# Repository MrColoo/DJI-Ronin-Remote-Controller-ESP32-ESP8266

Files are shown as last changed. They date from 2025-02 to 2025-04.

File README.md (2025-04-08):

# 🎮 DJI Ronin Remote Controller - ESP32/ESP8266




A wireless remote control solution for DJI Ronin gimbals using ESP8266/ESP32 microcontrollers and WebSocket communication.

## 📝 Description

This project enables wireless control of DJI Ronin gimbals through a network connection, utilizing the SBUS protocol. It creates a bridge between a WebSocket client (like Chataigne software) and the Ronin's SBUS input, allowing remote control via gamepad or other input devices.

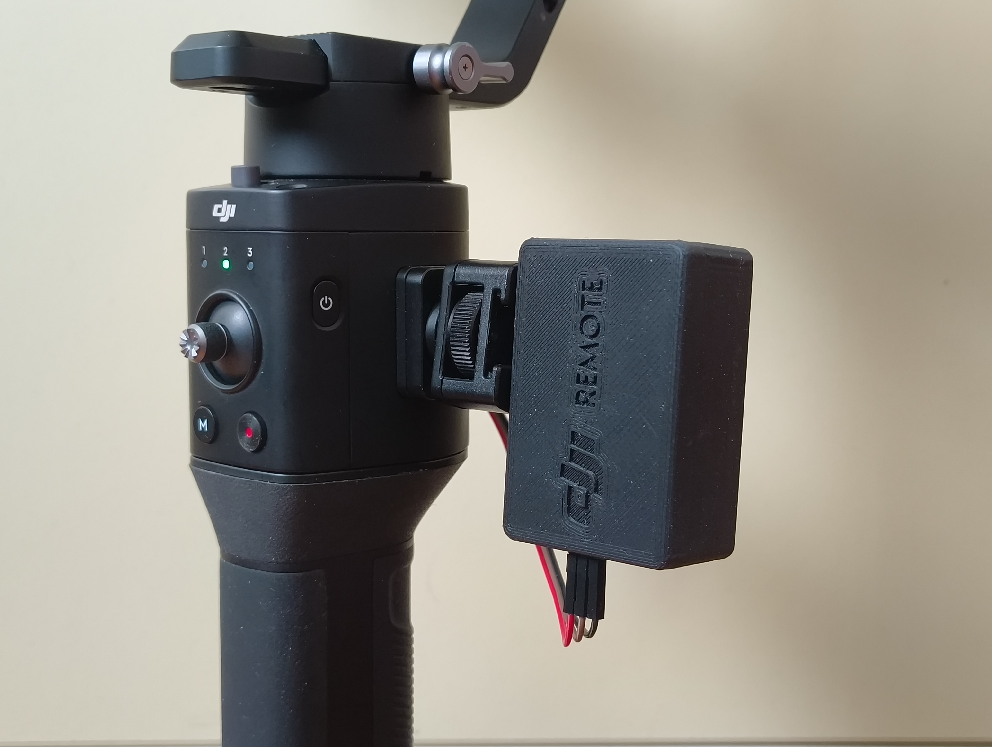
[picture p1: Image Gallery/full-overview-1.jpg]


### ✨ Features

- 🌐 WiFi configuration portal
- 📡 WebSocket server for real-time control
- 💾 Persistent WiFi settings storage
- 📊 Real-time logging interface
- 🔧 Static IP configuration
- 🔄 Easy reset functionality
- 🎮 Compatible with Chataigne software for gamepad input or any WebSocket clients

### 🎥 Demo Video

https://github.com/user-attachments/assets/ff83e8b6-8403-40a6-982f-c90003f82979

## 🛠️ Hardware Requirements

- ESP8266 or ESP32 microcontroller
- DJI Ronin gimbal (tested on Ronin SC, should work with other models)
- Connection cables
- 1x Transistor 2N2222
- 1x 1K Resistor
- 1x 5K Resistor  
NOTE: Have a look to wiring schema image

## 📋 Installation Guide

### 1. Hardware Setup

1. Connect the ESP board to the Ronin's SBUS port:
   - SBUS signal → Transistor 2N2222 or serial inverter (look at wiring schema) -> GPIO pin (as defined in code)
   - GND → GND
   - 5V → 5V (if needed)

NOTE: Have a look to wiring schema image

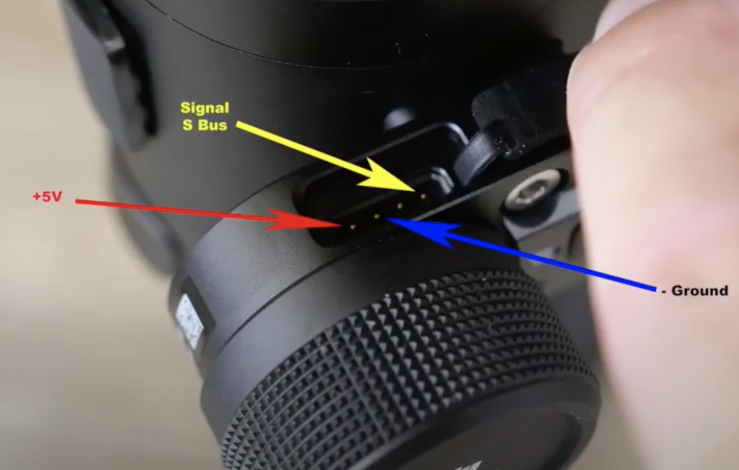
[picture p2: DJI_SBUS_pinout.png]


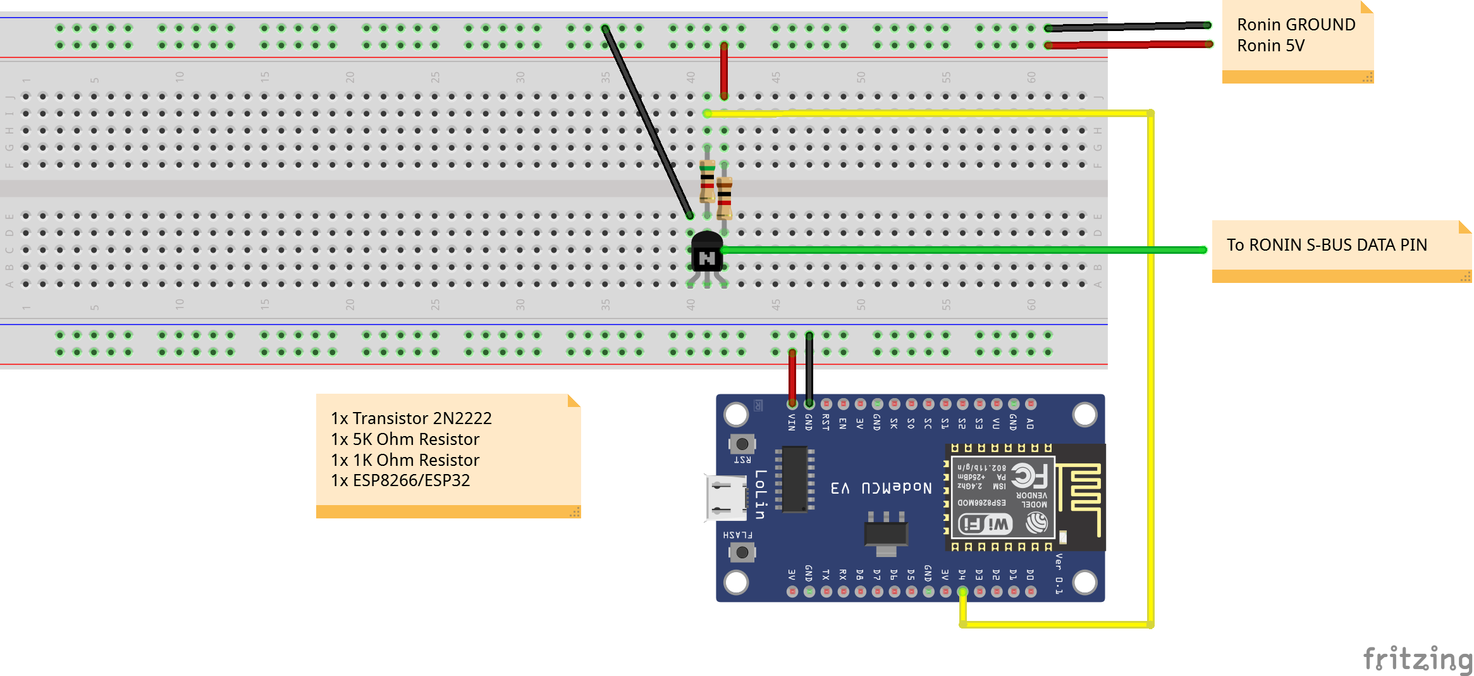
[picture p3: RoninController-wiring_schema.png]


### 2. Software Setup

1. Install required Arduino libraries:
   - ESP8266WiFi
   - ESP8266WebServer
   - DNSServer
   - EEPROM
   - WebSocketsServer
   - Ronin_SBUS // Copy the library folder under Code folder here on github and put into your libraries folder

2. Upload the code to your ESP device

### 3. Initial Configuration

1. Power up the device
2. Connect to the WiFi network "RoninControl_Setup"
3. Automatically the captive portal should open up, if it doesn't, open a web browser and navigate to `192.168.4.1`
4. Configure your WiFi settings:
   - Enter your network SSID and password
   - Optionally configure static IP
5. Save and wait for the device to restart
  
NOTE: ✔ If the ESP connects successfully to the wifi, the generated wifi will disappear.
     ❌ If the ESP can't connect to wifi after some attempts, it will restart in setup mode

## 🎮 Usage

### Normal Operation

1. The device will connect to your configured WiFi network
2. Access the web interface using the device's IP address
3. Available pages:
- Status page: Shows connection info and device status
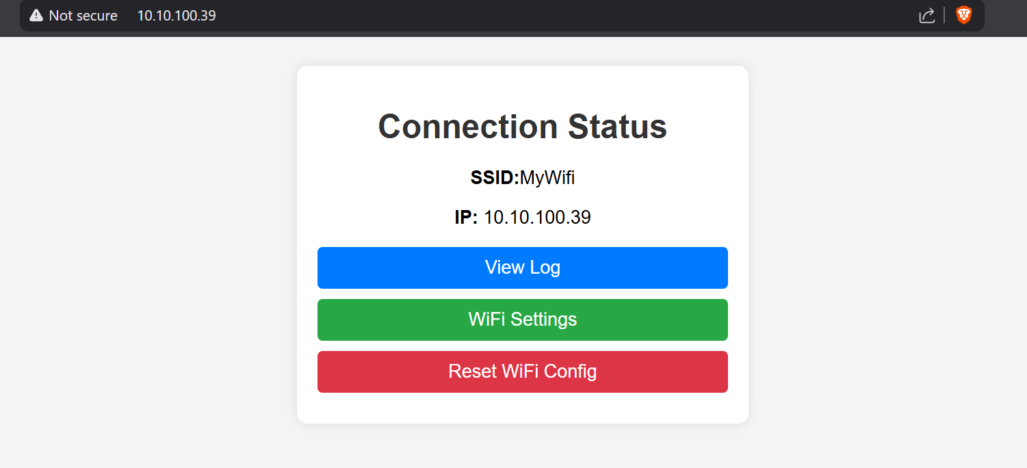
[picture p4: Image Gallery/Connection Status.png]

- Log page: Real-time operation logs
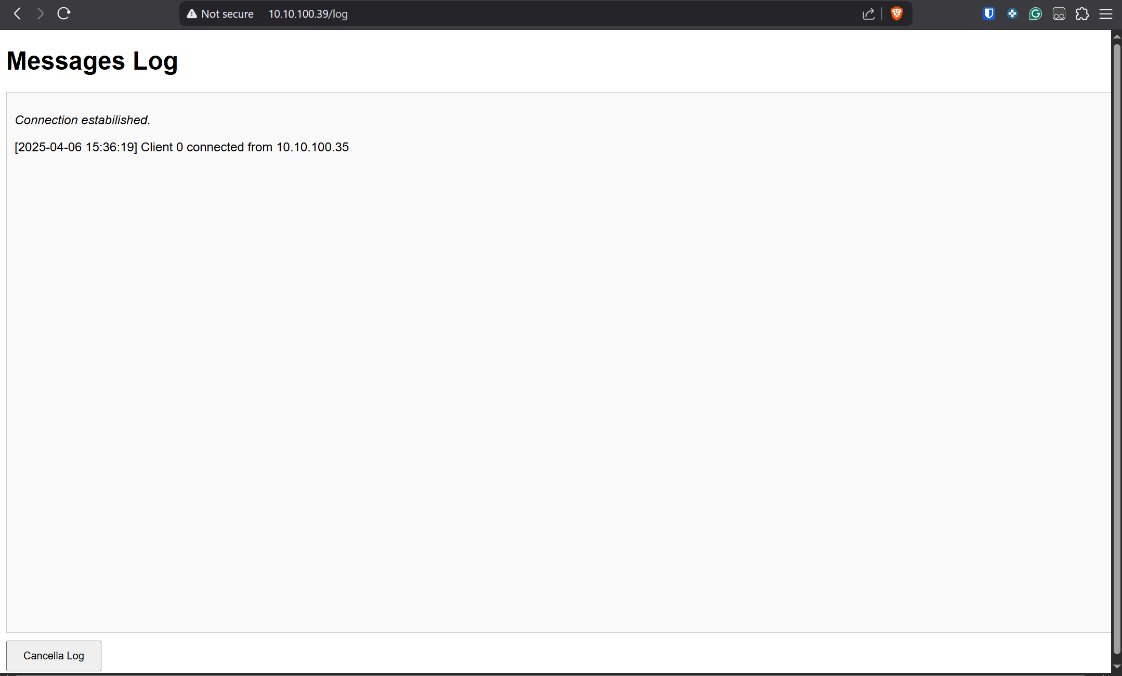
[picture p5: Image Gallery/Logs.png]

- WiFi Configuration: Network settings
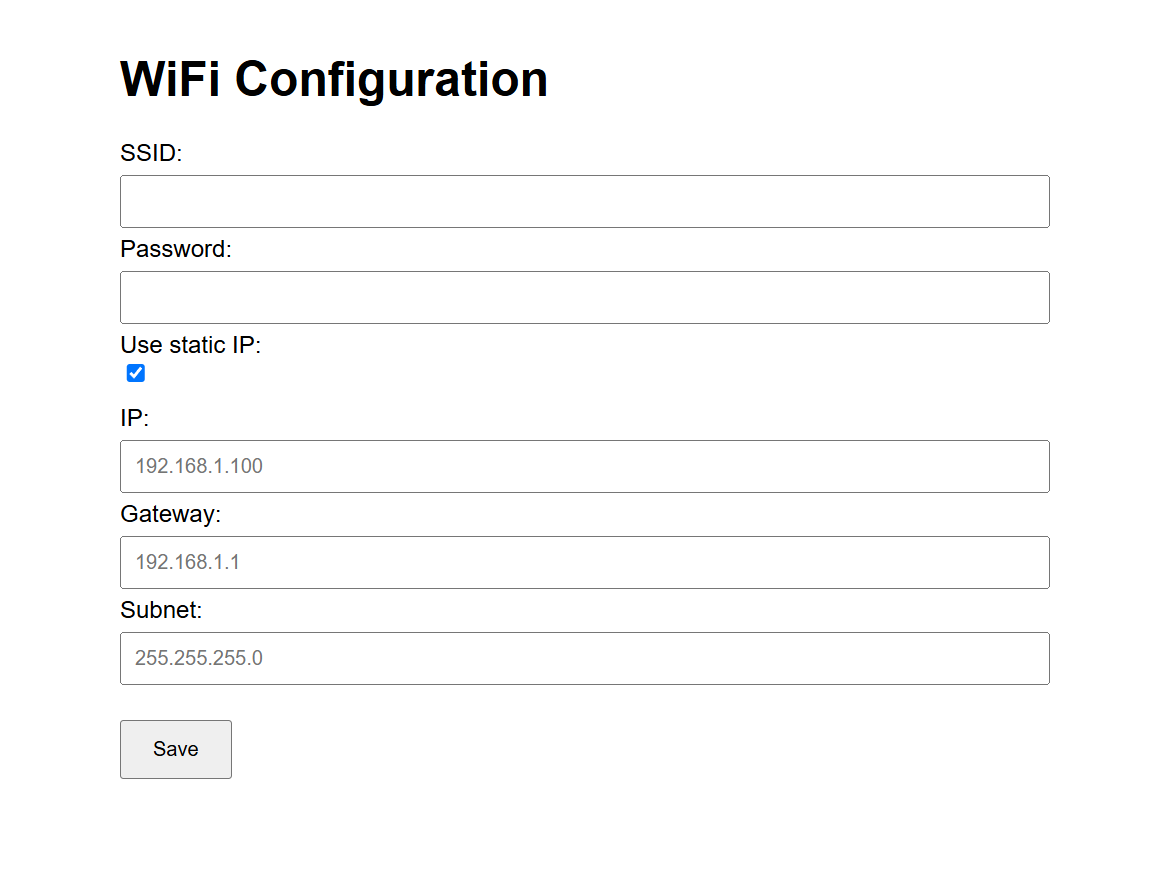
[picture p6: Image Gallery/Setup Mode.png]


### WebSocket Control

1. Connect to the WebSocket server on port 81
2. Send commands in format: `chX:VALUE` where:
- X: Channel number (1-16)
- VALUE: Position value (352-1696)

Example: `ch1:1024` sets channel 1 to center position

### Using with Chataigne

1. Download from this repo the setup file: `RONIN_CONTROL_Chataigne_SetupFile.noisette`
2. Configure Chataigne's WebSocket module to connect to the device
3. Map gamepad inputs to WebSocket messages
   -> Use the following value ranges:
      - Minimum: 352
      - Center: 1024
      - Maximum: 1696

NOTE: For Ronin SC I made only PAN and TILT work (channels 1 and 2)

## 🔧 Technical Details

### Key Components

- **WiFi Configuration**: Stores network settings in EEPROM
- **WebSocket Server**: Handles real-time control commands
- **SBUS Protocol**: Communicates with Ronin gimbal
- **Web Interface**: Provides configuration and monitoring

## 🐛 Known Bugs

1. The gimbal mode 2 is set by default and it is not changeable
2. If only one websocket movement command is sent (for ex. joystick stick all to the right), the gimbal will move and then stop after some seconds, instead of continuing to move.

## 🚧 Unimplemented Features (Work in progress)

1. Gimbal mode selector
2. Gimbal Recenter
3. Start and Stop Recording
4. Remote controlled motorized Zoom / Focus
5. Complete debug feature through logs
6. Extend complete compatibility to other Ronin models (right know only Ronin SC is supported without code modifications)

## ⚠️ Important Notes

- Tested primarily with DJI Ronin SC, but should work with other models, you may will have to adjust s-bus values in the Ronin_SBUS library
- Ensure a stable WiFi connection for reliable control
- Keep within range of the WiFi network
- Monitor the log interface for debugging

## 📚 Library

- Ronin_SBUS is a library I wrote, starting from the original [BMC_SBUS](https://github.com/boldstelvis/BMC_SBUS) library. Thanks to the developer.

## 🤝 Contributing

Contributions, issues, and feature requests are welcome!

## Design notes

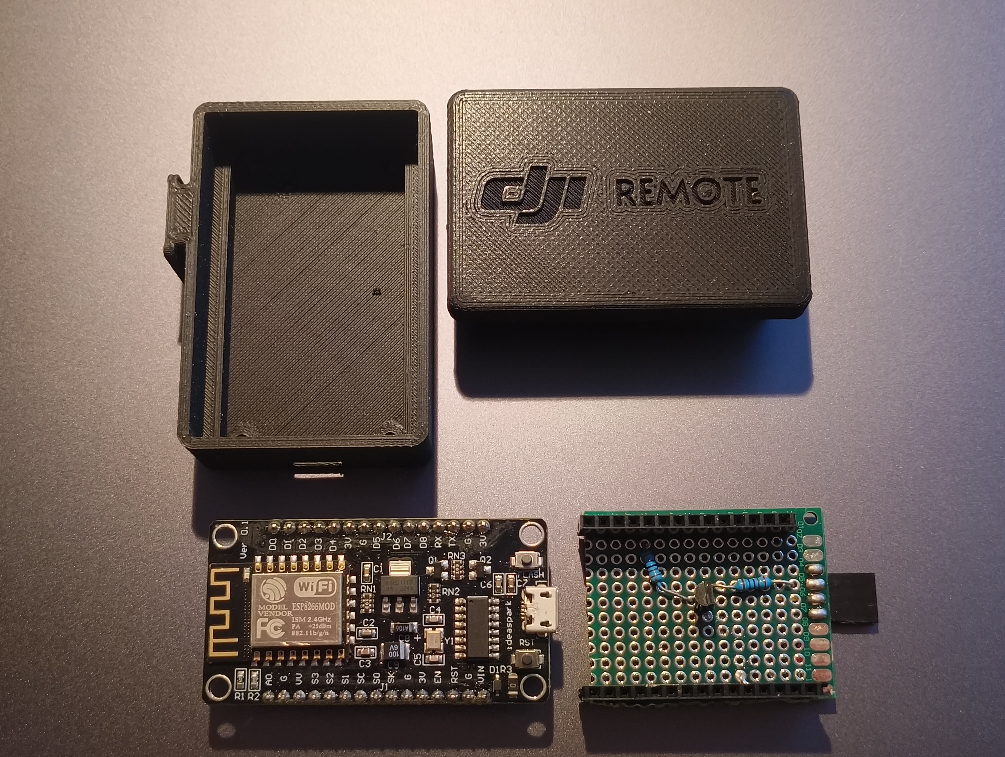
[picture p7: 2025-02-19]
Image Gallery/device-overview-2.jpg

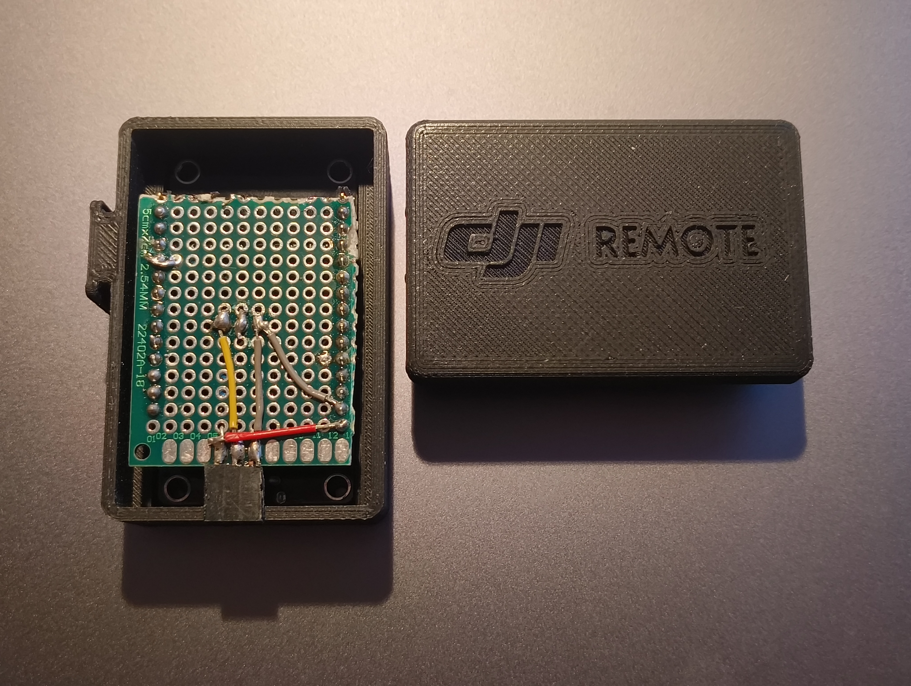
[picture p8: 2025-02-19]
Image Gallery/device-overview-3.jpg

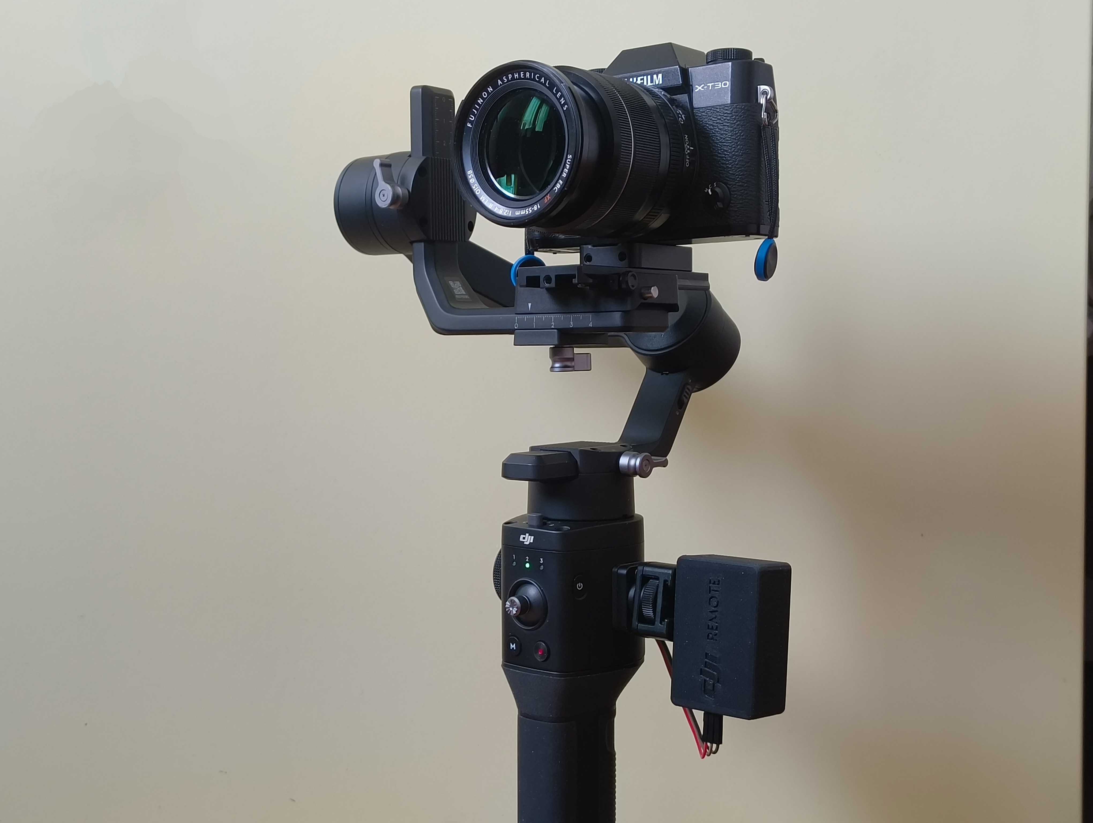
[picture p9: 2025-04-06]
Image Gallery/full-overview-2.jpg

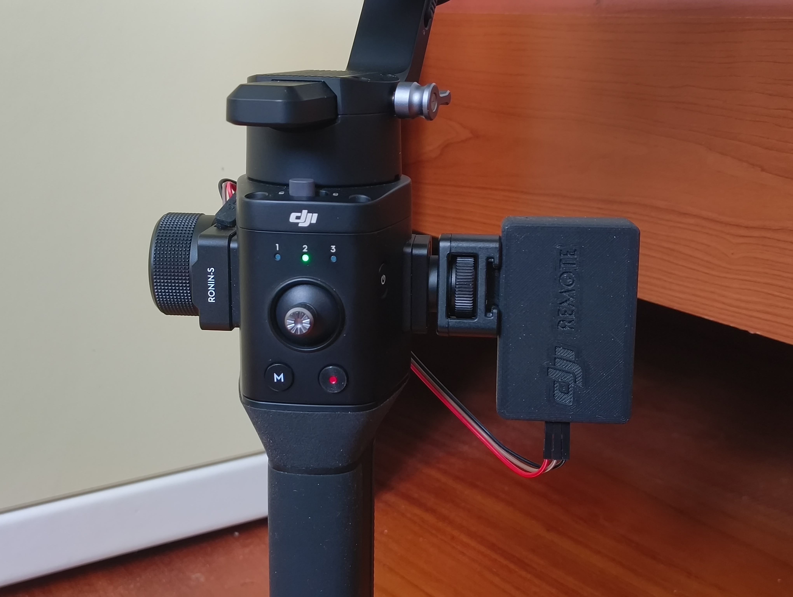
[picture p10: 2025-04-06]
Image Gallery/full-overview-5.jpg

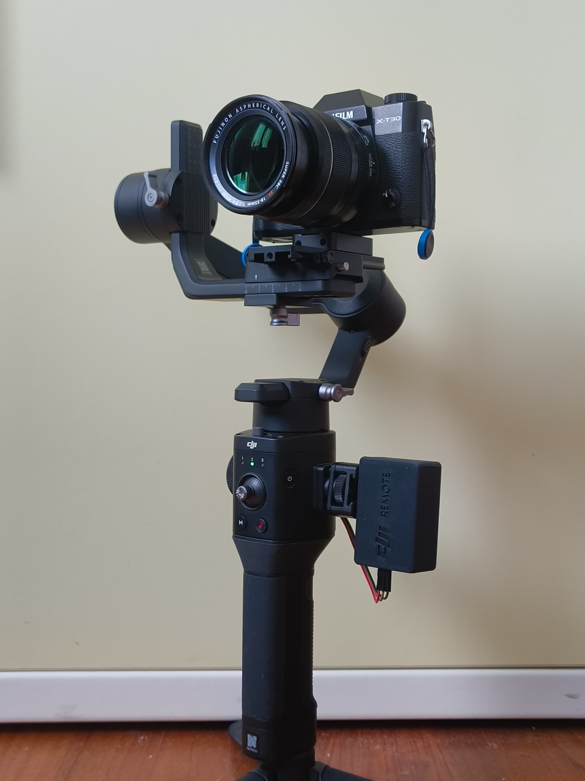
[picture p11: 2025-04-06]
Image Gallery/full-overview-3.jpg

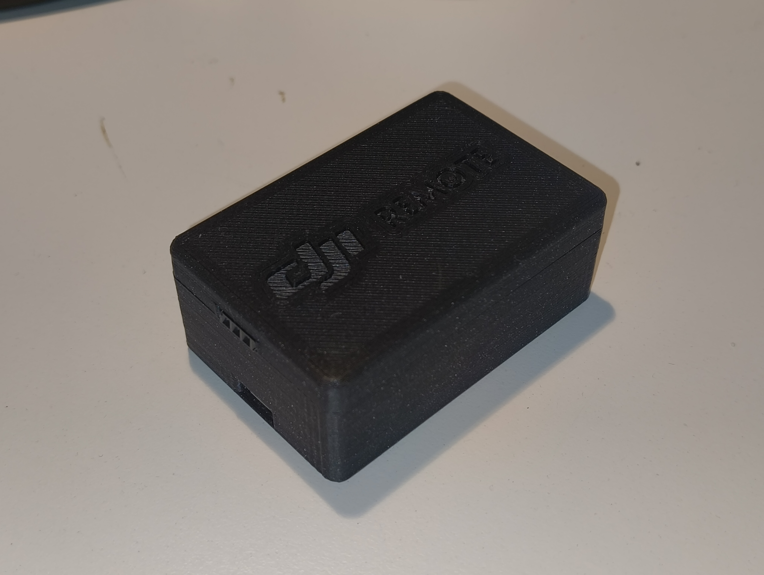
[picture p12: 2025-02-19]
Image Gallery/device-overview-4.jpg

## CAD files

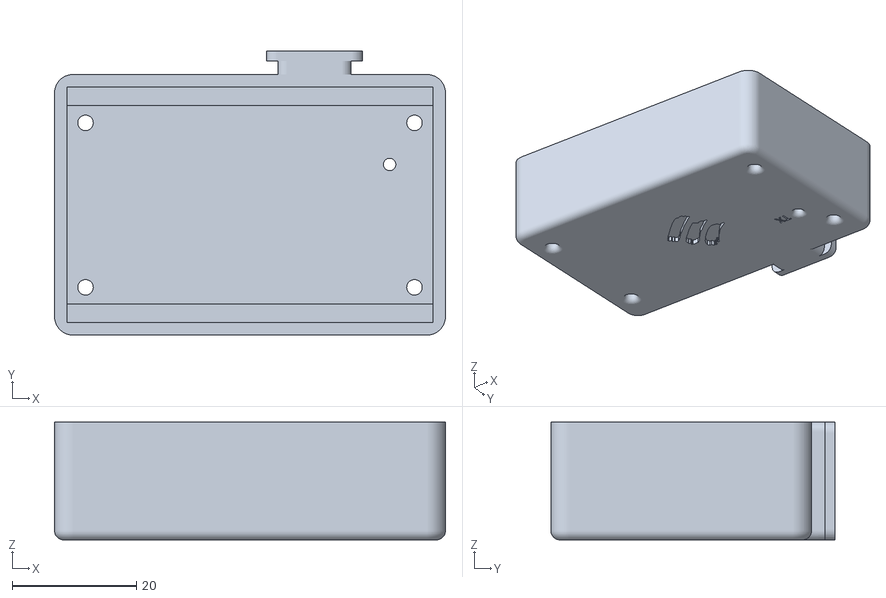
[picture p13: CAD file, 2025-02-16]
3D_CASE/Bottom CASE.stl
63.0 x 45.8 x 19.0

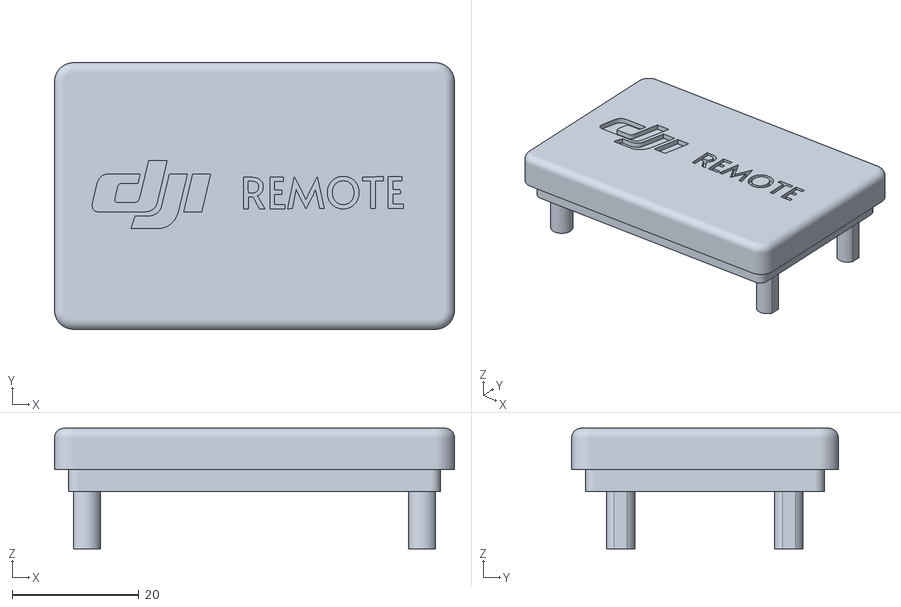
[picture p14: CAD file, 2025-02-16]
3D_CASE/Up Cover CASE.stl
63.0 x 42.0 x 19.0

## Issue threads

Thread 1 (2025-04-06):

A-B scene switching, connection details

abrman, 2025-04-06:
Hey! This project and readme looks incredibly well done. I'm sort-of using this to make an informed purchase of a DJI Ronin + Sony mirrorless camera or PTZ camera for live event streaming. I would love to go the Ronin + Camera as it's more versatile if PTZ like controls work, otherwise PTZ camera it is.

1. Is it possible to do A-B scene switching using this? (Preset pitch tilt zoom and transition to that point) I'm thinking sending three self-stored values via ws should work but due to lack of experience I'm asking specifically. - I suppose it's designed to work with Chatsigne software - will need to look into this

2. How does it connect to the Ronin - the attached images are very informative but once the connector leaves the ESP32/ESP8266 how does it connect to the ronin? Do I need to get an additional wire?

3. How's the reliability of the connection. I've had esp32 chips become unresponsive for some IOT applications in the past requiring reboot. Would it be possible to do a video demo on YouTube?

Love the work you did on this!
Thank you!

abrman, 2025-04-07:
Thank you for all the additional details. I've pondered on it for a bit as to whether it's a path forward for me.

From what you're saying it seems like the controls are setting a motor strength rather than monitoring Pitch Yaw Roll, very much like something a gimbal would be controlled by haha. I suppose internally the gimbal has to have an accelerometer or a gyroscope but the data isn't published by the Ronin.

I'm wondering if an additional gyroscope could achieve the functionality I'm seeking where it could feed the motor strength instead of user controls. I've been also toying with the idea of visual reference points and use the video signal to feed the controller data until desired view is achieved (rather complex even if permanent install in a studio is considered due to lighting and subjects so I'm not inclined to go this route)

https://randomnerdtutorials.com/esp32-mpu-6050-accelerometer-gyroscope-arduino/

The gyro would have to be installed somewhere on the camera. Ultimately the orientation shouldn't matter as the output can be transformed to zero out reading when pointing straight ahead. When "sceene switching" just zero out to a different point and the camera should transition assuming the gyro values influence the data passed to the gimbal.

Wiring is potentially an issues unless power is somehow received from the camera and data fed over Bluetooth back to the controller, although if HDMI wire is already connected to the camera, this might not be a big issue due to the wire restraint already being there, and an additional wire should be a problem.

Just sharing thought up until now. Let me know if you have any thoughts on anything said. - What are the limitations on roll. You do mention Pan and Tilt, is roll also configurable or is that managed automatically by the ronin keeping level with the horizon. What are the limitations for zoom control? I'm speaking out of lack of experience but my understanding is that zoom can be external via a motor (DJI has one I think?) or the lens needs to have motorized zoom. What are the obstacles in controlling zoom if that was a desired feature. Consider DJI Ronin Zoom control. Does it normally connect in the same place we're connecting for the S-Bus data pin? Would it be controllable?

Thank you for your work on this! I'm excited for this project as it seems like the best solution of all the other GitHub projects tacking the Ronin PTZ control problem.

MrColoo, 2025-04-08:
Excellent thoughts and ideas!

> I'm wondering if an additional gyroscope could achieve the functionality I'm seeking where it could feed the motor strength instead of user controls

As I said before, the ronin does not send any data, so if it has any kind of gyroscope or accelerometer is not usable.
This said, it is possible to add an external gyro to the gimbal and as you said before should be installed on the top or bottom of the camera. It will make the project more complicated, but everything is possible. On the camera mount there are two holes where it could be screwed on, but there would be other cables other than the HDMI (if they are thin, it should not be a problem)

> I've been also toying with the idea of visual reference points and use the video signal to feed the controller data until desired view is achieved (rather complex even if permanent install in a studio is considered due to lighting and subjects so I'm not inclined to go this route)

I think this would be a little overkill right now and would require more computational power to process all the images and algorithms...

>  What are the limitations on roll.
Unfortunately, I wasn't able to control the Roll axis through the SBUS interface on my Ronin SC, and some discussions on the DJI Forum confirm this, but it should work on the Ronin S series.

> What are the limitations for zoom control?
The stock follow focus / zoom motor is not usable through SBUS in any Ronin gimbal (idk why DJI does this to us...), so to implement this, we could use an external stepper motor mounted on the original bracket and attached directly to the ESP.

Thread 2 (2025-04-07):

S-BUS Connection 4pin, but 3 wires

paulprinke, 2025-04-07:
I am trying to get this setup locally and I cant find a map of what the layout of the SBUS on the gimbal (focus knob) to then match your wiring schematic.  Do you have this handy or could you add some additional details to your README?

I think I have the wiring done, but concerned connecting to just random pins to try.  (Using an ESP32C3)

MrColoo, 2025-04-08:
Hi! Thanks for your interest for the project. I've just updated the readme with more images about the wiring and the pinout of the ronin focus know. Let me know if now is more understandable

Closed 2025-04-08.

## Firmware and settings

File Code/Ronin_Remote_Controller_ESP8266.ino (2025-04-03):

#include <ESP8266WiFi.h>
#include <ESP8266WebServer.h>
#include <DNSServer.h>
#include <EEPROM.h>
#include <WebSocketsServer.h>
#include <Ronin_SBUS.h>

// Access Point Setup
const char* AP_SSID = "RoninControl_Setup";
const byte DNS_PORT = 53;
IPAddress apIP(192, 168, 4, 1);

// Server and DNS
ESP8266WebServer webServer(80);
DNSServer dnsServer;

// WebSockets Server
WebSocketsServer webSocket = WebSocketsServer(81); // Porta 81 per WebSockets

// Struct to save wifi config
struct WifiConfig {
    char wifi_ssid[32];
    char wifi_password[64];
    bool use_static_ip;
    IPAddress static_ip;
    IPAddress gateway;
    IPAddress subnet;
    uint8_t config_set;  // Flag per verificare se la configurazione è stata impostata
};

// Initialize wificonfig struct
WifiConfig wificonfig;

// Initialize SBUS interface
Ronin_SBUS mySBUS;

// Constants used to define min, mid and max values & frame delay
const int sbusMID         = 1024;   // Neutral val
const int sbusMIN         = 352;    // Min usable for analog val and switch val
const int sbusMAX         = 1696;   // Max usable for analog val and switch val
const int sbusWAIT        = 10;     // Frame timing delay in msecs

// Function to send logs throw WebSocket with timestamp, visible in webpage/log
void sendLog(String message) {
    // Get current time
    time_t now = time(nullptr);
    struct tm* timeinfo = localtime(&now);
    
    // Timestamp format
    char timeString[20];
    strftime(timeString, sizeof(timeString), "%Y-%m-%d %H:%M:%S", timeinfo);
    
    // Write formatted message
    String formattedMessage = String("[") + String(timeString) + "] " + message;
    webSocket.broadcastTXT(formattedMessage);
}

void setup() {
    // Inizialize EEPROM
    EEPROM.begin(512);
    // Initialize USB serial for debug
    // Serial.begin(9600); // Uncomment if you want to debug via serial console

    // Load saved wifi settings
    loadWifiConfig();

    // Initialize SBUS 
    mySBUS.begin();

    if (wificonfig.config_set != 1) {
        startSetupMode();
    } else {
        startNormalMode();
    }
}

// Function to load wifi config from the struct
void loadWifiConfig() {
    EEPROM.get(0, wificonfig);
    if (wificonfig.config_set != 1) {
        wificonfig.config_set = 0;
        wificonfig.use_static_ip = false;
        strcpy(wificonfig.wifi_ssid, ""); // Vuoto per configurazione
        strcpy(wificonfig.wifi_password, ""); // Vuoto per configurazione
        wificonfig.static_ip = IPAddress(192, 168, 1, 200);
        wificonfig.gateway = IPAddress(192, 168, 1, 1);
        wificonfig.subnet = IPAddress(255, 255, 255, 0);
    }
}

void saveWifiConfig() {
    EEPROM.put(0, wificonfig);
    EEPROM.commit();
}

// Function to start the ESP in setup mode --> generate open wifi ("RoninControl_Setup") to set up network settings
void startSetupMode() {
    WiFi.mode(WIFI_AP);
    WiFi.softAPConfig(apIP, apIP, IPAddress(255, 255, 255, 0));
    WiFi.softAP(AP_SSID);
    dnsServer.start(DNS_PORT, "*", apIP);

    webServer.on("/", handleSetupRoot);
    webServer.on("/configure", handleConfigure);
    webServer.on("/reset", handleReset);
    webServer.onNotFound([]() { 
        webServer.sendHeader("Location", "/", true);
        webServer.send(302, "text/plain", ""); 
    });
    webServer.begin();
    sendLog("Setup mode started");
}

// Function to start the ESP in normal mode --> if it cannot connect within 25 attemps, it will restart in setup mode
void startNormalMode() {
    WiFi.mode(WIFI_STA);
    if (wificonfig.use_static_ip) {
        WiFi.config(wificonfig.static_ip, wificonfig.gateway, wificonfig.subnet);
    }
    WiFi.begin(wificonfig.wifi_ssid, wificonfig.wifi_password);
    sendLog("Connecting to wifi: " + String(wificonfig.wifi_ssid));
    int attempts = 0;
    while (WiFi.status() != WL_CONNECTED && attempts < 25) {
        delay(1000);
        sendLog("Connection attemp #" + attempts);
        attempts++;
    }
    if (WiFi.status() == WL_CONNECTED) {
        configTime(3600, 0, "pool.ntp.org", "time.nist.gov");

        sendLog("Connected to " + String(wificonfig.wifi_ssid));
        sendLog("IP: " + WiFi.localIP().toString());

        // Setting up WebServer routes
        webServer.on("/", handleStatusRoot);
        webServer.on("/configure", handleConfigure);
        webServer.on("/reset", handleReset);
        webServer.on("/log", handleLogPage);
        webServer.on("/wificonfig", handleWifiConfig);
        webServer.begin();

        // Initialize WebSocket
        webSocket.begin();
        webSocket.onEvent(webSocketEvent);
        sendLog("WebSocket Server started on port 81");
    } else {
        sendLog("Connection failed, starting setup mode");
        handleReset();
        startSetupMode();
    }
}

// Setup page handling
void handleSetupRoot() {
    webServer.send(200, "text/html",
        "<!DOCTYPE html>"
        "<html>"
        "<head>"
        "  <title>WiFi Configuration</title>"
        "  <style>"
        "    body { font-family: Arial, sans-serif; max-width: 600px; margin: auto; padding: 20px; }"
        "    input[type=text], input[type=password] { width: 100%; padding: 8px; margin: 5px 0; }"
        "    input[type=submit] { padding: 10px 20px; }"
        "  </style>"
        "</head>"
        "<body>"
        "  <h1>WiFi Configuration</h1>"
        "  <form id='wifiForm' action='/configure' method='POST'>"
        "    <label>SSID:</label><br>"
        "    <input type='text' name='ssid' required><br>"
        "    <label>Password:</label><br>"
        "    <input type='password' name='password' required><br>"
        "    <label>Use static IP:</label><br>"
        "    <input type='checkbox' name='static_ip' id='static_ip'><br>"
        "    <div id='static_ip_fields' style='display:none; margin-top:10px;'>"
        "      <label>IP:</label><br>"
        "      <input type='text' name='ip' placeholder='192.168.1.100'><br>"
        "      <label>Gateway:</label><br>"
        "      <input type='text' name='gateway' placeholder='192.168.1.1'><br>"
        "      <label>Subnet:</label><br>"
        "      <input type='text' name='subnet' placeholder='255.255.255.0'><br>"
        "    </div>"
        "    <br>"
        "    <input type='submit' value='Save'>"
        "  </form>"
        "  <script>"
        "    document.getElementById('static_ip').addEventListener('change', function() {"
        "      document.getElementById('static_ip_fields').style.display = this.checked ? 'block' : 'none';"
        "    });"
        "    document.getElementById('wifiForm').addEventListener('submit', function(event) {"
        "      alert('Configuration Saved!\\nThe device will reboot and try to connect to WiFi.\\nIf something goes wrong, it will restart in setup mode.');"
        "    });"
        "  </script>"
        "</body>"
        "</html>"
    );
}

// Status page handling
void handleStatusRoot() {
    String page = "<!DOCTYPE html>"
                  "<html>"
                  "<head>"
                  "<title>Connection Status</title>"
                  "<style>"
                  "  body { font-family: Arial, sans-serif; text-align: center; padding: 20px; background-color: #f4f4f4; }"
                  "  .container { max-width: 400px; margin: auto; background: white; padding: 20px; border-radius: 10px; box-shadow: 0 0 10px rgba(0,0,0,0.1); }"
                  "  h1 { color: #333; }"
                  "  p { font-size: 18px; }"
                  "  .button { display: block; width: 100%; padding: 10px; margin: 10px 0; border: none; border-radius: 5px; font-size: 18px; text-decoration: none; cursor: pointer; text-align: center; }"
                  "  .btn-log { background-color: #007bff; color: white; }"
                  "  .btn-config { background-color: #28a745; color: white; }"
                  "  .btn-reset { background-color: #dc3545; color: white; }"
                  "</style>"
                  "</head>"
                  "<body>"
                  "<div class='container'>"
                  "  <h1>Connection Status</h1>"
                  "  <p><strong>SSID:</strong> " + String(WiFi.SSID()) + "</p>"
                  "  <p><strong>IP:</strong> " + WiFi.localIP().toString() + "</p>"
                  "  <button class='button btn-log' onclick='logRedirect()'>View Log</button>"
                  "  <button class='button btn-config' onclick='configRedirect()'>WiFi Settings</button>"
                  "  <button class='button btn-reset' onclick='confirmReset()'>Reset WiFi Config</button>"
                  "</div>"
                  "<script>"
                  "  function confirmReset() {"
                  "    if (confirm('WiFi configuration will be reset and the device will reboot in setup mode. Continue?')) {"
                  "      setTimeout(() => { window.location.href = '/reset'; }, 500);"
                  "      setTimeout(() => { window.close(); }, 1000);"
                  "    }"
                  "  }"
                  "  function logRedirect() {"
                  "     window.location.href = '/log';"
                  "  }"
                  "  function configRedirect() {"
                  "     window.location.href = '/wificonfig';"
                  "  }"
                  "</script>"
                  "</body>"
                  "</html>";

    webServer.send(200, "text/html", page);
}

void handleWifiConfig() {
    String page = "<!DOCTYPE html>"
        "<html>"
        "<head>"
        "  <title>WiFi Configuration</title>"
        "  <style>"
        "    body { font-family: Arial, sans-serif; max-width: 600px; margin: auto; padding: 20px; }"
        "    input[type=text], input[type=password] { width: 100%; padding: 8px; margin: 5px 0; }"
        "    input[type=submit] { padding: 10px 20px; }"
        "  </style>"
        "</head>"
        "<body>"
        "  <h1>WiFi Configuration</h1>"
        "  <form id='wifiForm' action='/configure' method='POST'>"
        "    <label>SSID:</label><br>"
        "    <input type='text' name='ssid' value='" + String(wificonfig.wifi_ssid) + "' disabled><br>"
        "    <div id='static_ip_fields' style='display:block; margin-top:10px;'>"
        "      <label>IP:</label><br>"
        "      <input type='text' name='ip' value='" + WiFi.localIP().toString() + "' required><br>"
        "      <label>Gateway:</label><br>"
        "      <input type='text' name='gateway' value='" + WiFi.gatewayIP().toString() + "' required><br>"
        "      <label>Subnet:</label><br>"
        "      <input type='text' name='subnet' value='" + WiFi.subnetMask().toString() + "' required><br>"
        "    </div>"
        "    <br>"
        "    <input type='submit' value='Save'>"
        "  </form>"
        "  <script>"
        "    document.getElementById('wifiForm').addEventListener('submit', function(event) {"
        "      alert('Configuration Saved!\\nThe device will reboot and try to connect to WiFi.\\nIf something goes wrong, it will restart in setup mode.');"
        "    });"
        "  </script>"
        "</body>"
        "</html>";

    webServer.send(200, "text/html", page);
}

// Log page handling
void handleLogPage() {
    String page = R"rawliteral(
<!DOCTYPE html>
<html>
<head>
    <title>Messages Log</title>
    <style>
        body { font-family: Arial, sans-serif; }
        #logs { width: 100%; height: 80vh; border: 1px solid #ccc; overflow-y: scroll; padding: 10px; background-color: #f9f9f9; }
        #clearButton { margin-top: 10px; padding: 10px 20px; }
        button { cursor: pointer; }
    </style>
</head>
<body>
    <h1>Messages Log</h1>
    <div id="logs"></div>
    <button id="clearButton">Cancella Log</button>

    <script>
        let socket = new WebSocket('ws://' + location.hostname + ':81/');
        let logs = document.getElementById('logs');
        let clearButton = document.getElementById('clearButton');

        socket.onopen = function(event) {
            logs.innerHTML += '<p><em>Connection estabilished.</em></p>';
        };

        socket.onmessage = function(event) {
            logs.innerHTML += '<p>' + event.data + '</p>';
            logs.scrollTop = logs.scrollHeight; // Scorri automaticamente verso il basso
        };

        socket.onclose = function(event) {
            logs.innerHTML += '<p><em>Connection closed.</em></p>';
        };

        clearButton.addEventListener('click', function() {
            logs.innerHTML = '';
            // Optional: Send a message to server when clear button is pressed
            // socket.send('clear');
        });
    </script>
</body>
</html>
)rawliteral";

    webServer.send(200, "text/html", page);
}

// WiFi Configuration handling (receives data from POST form)
void handleConfigure() {
    // Form Data
    String ssid = webServer.arg("ssid");
    String password = webServer.arg("password");
    bool use_static_ip = webServer.hasArg("static_ip");
    String ip = webServer.arg("ip");
    String gateway = webServer.arg("gateway");
    String subnet = webServer.arg("subnet");

    if(wificonfig.config_set == 0){
      if (ssid.length() > 0 && password.length() > 0) {
        strncpy(wificonfig.wifi_ssid, ssid.c_str(), sizeof(wificonfig.wifi_ssid));
        strncpy(wificonfig.wifi_password, password.c_str(), sizeof(wificonfig.wifi_password));
        wificonfig.use_static_ip = use_static_ip;
        if (use_static_ip) {
            wificonfig.static_ip = parseIPAddress(ip);
            wificonfig.gateway = parseIPAddress(gateway);
            wificonfig.subnet = parseIPAddress(subnet);
        }
        wificonfig.config_set = 1;
      } else {
        webServer.send(400, "text/plain", "SSID and Password are required.");
        return;
      }
    }else{
      if (ip.length() > 0 && gateway.length() > 0 && subnet.length() > 0) {
        wificonfig.static_ip = parseIPAddress(ip);
        wificonfig.gateway = parseIPAddress(gateway);
        wificonfig.subnet = parseIPAddress(subnet);
        wificonfig.use_static_ip = true;
      } else {
        webServer.send(400, "text/plain", "IP Address, Gateway and Subnet are required.");
        return;
      }
    }
      
      saveWifiConfig();
      sendLog("WiFi config saved. Reboot...");
      webServer.sendHeader("Location", "/", true);
      webServer.send(302, "text/plain", "WiFi config saved. Reboot...");
      delay(1000);
      ESP.restart();
}

// Parsing IP from string
IPAddress parseIPAddress(String ip) {
    IPAddress result;
    result.fromString(ip);
    return result;
}

// Handling reset via web
void handleReset() {
    // Configurations reset
    memset(&wificonfig, 0, sizeof(wificonfig));
    saveWifiConfig();
    sendLog("WiFi config resetted. Reboot...");
    webServer.sendHeader("Location", "/", true);
    webServer.send(302, "text/plain", "WiFi config resetted. Reboot...");
    delay(1000);
    ESP.restart();
}

// Handling WebSocket events
void webSocketEvent(uint8_t num, WStype_t type, uint8_t * payload, size_t length) {
    switch(type) {
        case WStype_DISCONNECTED:
            sendLog("Client WebSocket " + String(num) + " Disconnected");
            break;
        case WStype_CONNECTED: {
            IPAddress ip = webSocket.remoteIP(num);
            sendLog("Client " + String(num) + " connected from " + String(ip[0]) + "." + String(ip[1]) + "." + String(ip[2]) + "." + String(ip[3]));
            break;
        }
        case WStype_TEXT:
            sendLog("WebSocket message received: " + String((char*)payload));
            handleWebSocketMessage((char*)payload);
            break;
    }
}

// Gestione dei messaggi WebSocket
void handleWebSocketMessage(char* msg) {
    // Message is supposed to be in the format "ch1:1600"
    // Es. "ch1:1600"

    // Convert message in string
    String message = String(msg);

    // Verify if message contains the separator ":"
    int separatorIndex = message.indexOf(':');
    if (separatorIndex == -1) {
        sendLog("Message format not valid!");
        return;
    }

    // Extract the channel number and its value
    int channel = message.substring(2, separatorIndex).toInt();
    int value = message.substring(separatorIndex + 1).toInt();

    // Control if value is in the allowed range
    if (value < sbusMIN || value > sbusMAX) {
        sendLog("Value out of allowed range!");
        return;
    }

    // Control if channel number is in the allowed range
    if (channel < 0 || channel > 16) {
        sendLog("Channel number out of allowed range!");
        return;
    }

    // print in logs received value
    sendLog("Channel:" + String(channel) +", Value: " + String(value));

    mySBUS.SetValue(channel, value);
    mySBUS.Update();
    mySBUS.Send(); // Send S-BUS frame to Ronin
    delay(sbusWAIT); // Wait for S-BUS frame transmission

}

void loop() {
    dnsServer.processNextRequest();
    webServer.handleClient();
    webSocket.loop(); // Manage WebSocket comunications
}

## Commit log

2025-02-19 Rename Bottom DEF.stl to Bottom CASE.stl
    [Bottom CASE.stl]
2025-02-19 Rename Up Cover DEF.stl to Up Cover CASE.stl
    [Up Cover CASE.stl]

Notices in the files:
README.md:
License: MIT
